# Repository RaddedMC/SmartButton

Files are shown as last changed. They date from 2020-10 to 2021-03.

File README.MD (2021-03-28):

# RaddedMC's SmartButton
This project is currently a work-in-progress. Most things work but there are a few small things to be ironed out...
Requirements:
 - An ESP32 or ESP8266 Microcontroller
 - An internet connection / WiFi router
 - Some webhooks!
 - Some kind of button -- the PCB is designed for a stanard 6x6mm tactile switch
 - Also helpful to have an LED and/or passive piezo -- the PCB is designed for a Murata PKMCS0909E4000-R1
 - Two resistors; values will vary, but the schematic has a 220 and 320 ohm. Use a resistor appropriate for your LED
 
Instructions:
 - Build the below circuit:
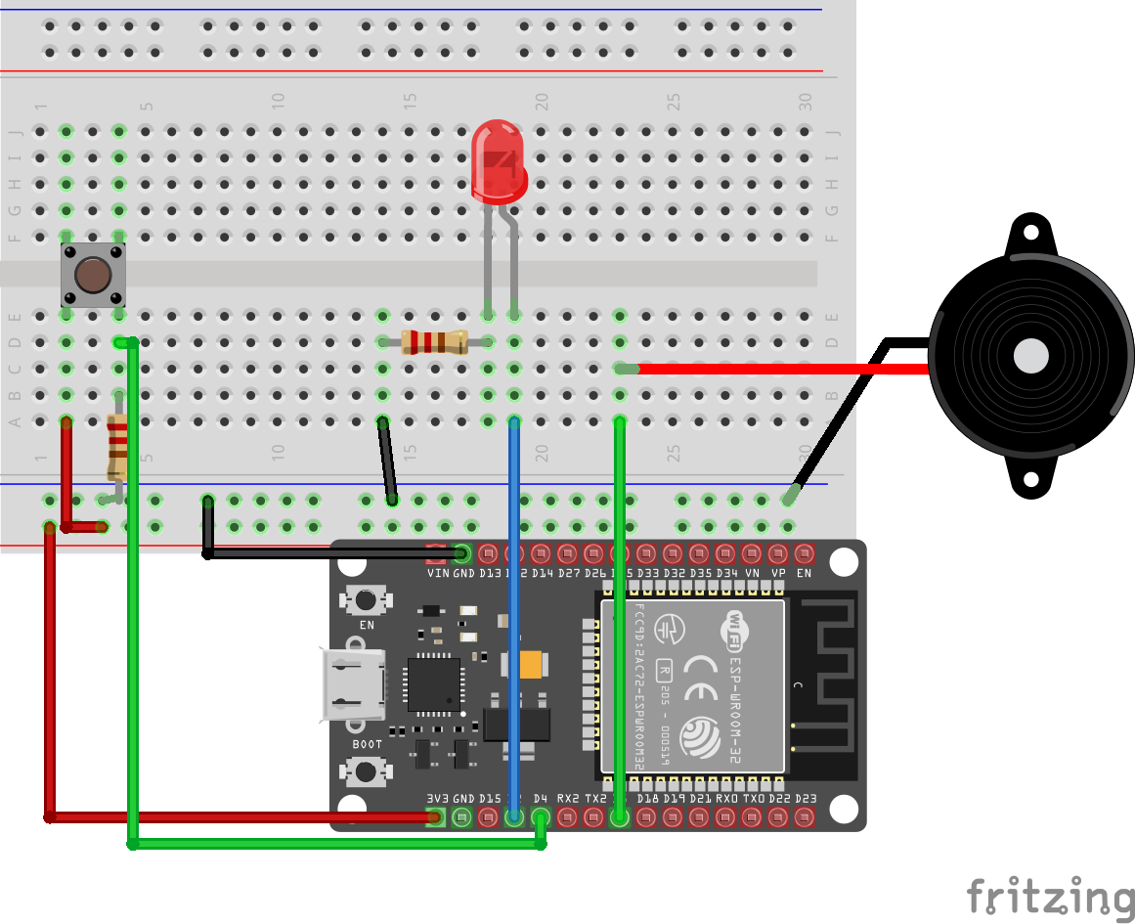
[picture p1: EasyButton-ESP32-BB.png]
Fritzing diagram of RaddedMC's SmartButton circuit
 
   - If you're using an ESP8266 NodeMCU, substitute D2, D4, and D6 with the pins labelled D4, D2, and D1 respectively. The LED resistor is 320 ohm and the button pulldown resistor is 220 ohm, however, these are not strict values
   - **OR** use the PCB in the PCB folder, credits to kelvinhall05 for the design!
 - Clone the EasyButton.ino file that matches your board
 - Make sure your Arduino IDE is set up for an ESP32 or ESP8266 NodeMCU board
 - Set Wifi SSID and password, and set up webhooks of your choosing (make sure that you use http:// in your URL as opposed to https://. 
 - You can change pins to whatever you like. Helpful if you want the ESP's built-in LED to blink when you do things or if you want to use one of the touch sensor pins instead of a boring clicky button. Pinout is currently configured for both boards to be compatible with one PCB.
 
**As mentioned, this project is a work in progress. Suggestions are appreciated, and these instructions might change over time.**

Feel free to dm me on Insta @RaddedMC or Discord at RaddedMC#4791 for any questions. Video for this project is in the works!

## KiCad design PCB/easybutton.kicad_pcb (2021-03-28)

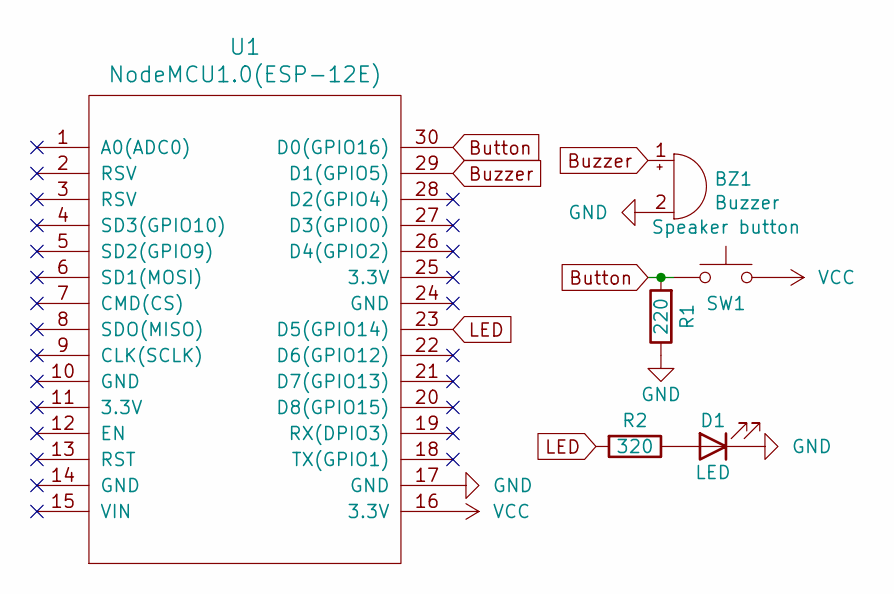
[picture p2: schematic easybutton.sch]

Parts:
BZ1: Buzzer; Buzzer_Murata_PKMCS0909E4000-R1
D1: LED; LED_D5.0mm
R1: 220; R_Axial_DIN0207_L6.3mm_D2.5mm_P10.16mm_Horizontal
R2: 320; R_Axial_DIN0207_L6.3mm_D2.5mm_P10.16mm_Horizontal
SW1: Speaker button; SW_PUSH_6mm
U1: NodeMCU1.0(ESP-12E); NodeMCU-LoLinV3

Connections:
Button: R1.2, SW1.1, U1.30 (D0(GPIO16))
Buzzer: BZ1.1 (-), U1.29 (D1(GPIO5))
GND: BZ1.2 (+), D1.1 (K), R1.1, U1.17 (GND)
LED: R2.2, U1.23 (D5(GPIO14))
unnamed: D1.2 (A), R2.1
VCC: SW1.2, U1.16 (3.3V)

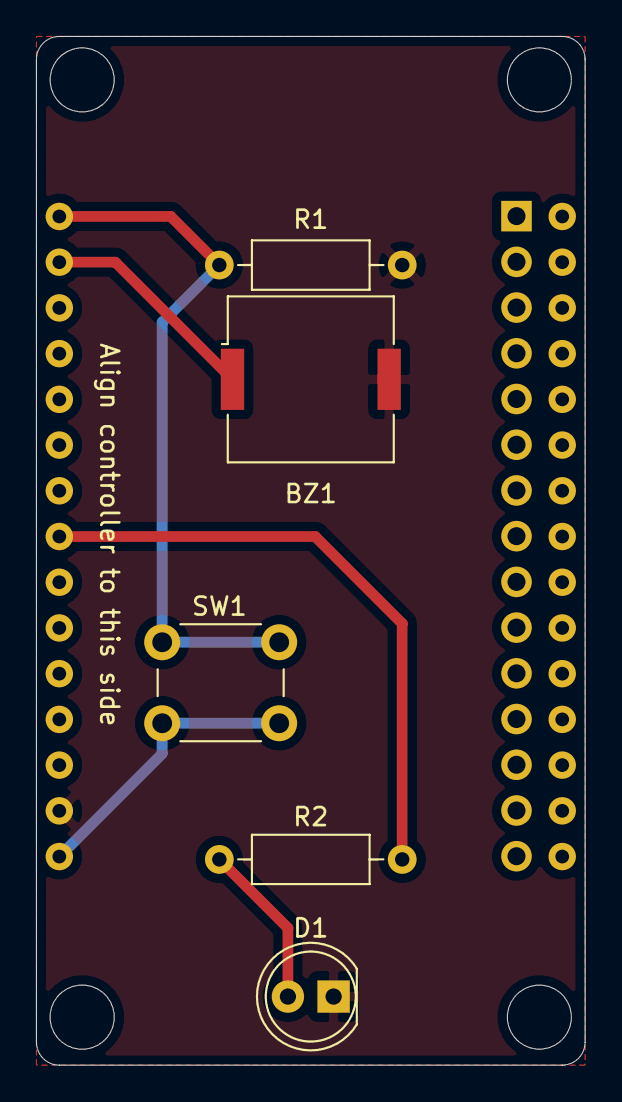
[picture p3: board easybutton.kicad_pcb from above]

Board: 2 copper layers, 30.5 x 57.2 mm, 6 parts (1 on the bottom side), 6 nets.

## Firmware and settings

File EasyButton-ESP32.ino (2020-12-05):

//EasyButton.ino for ESP32 -- RaddedMC


// META
#include <WiFi.h>
#include <HTTPClient.h>
const int BUTTON_PIN = 23;
const int BUZZER_PIN = 22;
const String WIFI_SSD = "Not2";
const String WIFI_PWD = "845NotNewpass7910";
const int LED_PIN = 5;

void printline(int spacing) {
  for (int i = 0; i != 30; i++) {
    if (i % spacing == 0) {
      Serial.print('-');
    } else {
      Serial.print(' ');
    }
  }
  Serial.println();
}
void printline() {
  printline(1);
}

// USER RESPONSE
void beep(int soundNum) {
  switch (soundNum) {
    case 0:
      // generic boop
      ledcWriteTone(0, 400);
      digitalWrite(LED_PIN, HIGH);
      delay(60);
      ledcWriteTone(0, 0);
      digitalWrite(LED_PIN, LOW);
      delay(100);
      break;
    case 1:
      // success tone 1 -- on
      ledcWriteTone(0, 400);
      digitalWrite(LED_PIN, HIGH);
      delay(100);
      ledcWriteTone(0, 0);
      digitalWrite(LED_PIN, LOW);
      delay(30);
      ledcWriteTone(0, 1000);
      digitalWrite(LED_PIN, HIGH);
      delay(80);
      ledcWriteTone(0, 0);
      digitalWrite(LED_PIN, LOW);
      delay(100);
      break;
    case 2:
      // fail tone
      ledcWriteTone(0, 1000);
      digitalWrite(LED_PIN, HIGH);
      delay(80);
      ledcWriteTone(0, 0);
      digitalWrite(LED_PIN, LOW);
      delay(100);
      ledcWriteTone(0, 400);
      digitalWrite(LED_PIN, HIGH);
      delay(400);
      ledcWriteTone(0, 0);
      digitalWrite(LED_PIN, LOW);
      delay(100);
      break;
    case 3:
      // boot tone
      //Megalovania?? yup https://github.com/AnonymousAlly/Arduino-Music-Codes/blob/master/Megalovania.ino
      ledcWriteTone(0,294);//D4
      digitalWrite(LED_PIN, HIGH);
      delay(125);
      ledcWriteTone(0, 0);
      digitalWrite(LED_PIN, LOW);
      delay(125);
      ledcWriteTone(0,294);//D4
      digitalWrite(LED_PIN, HIGH);
      delay(125);
      ledcWriteTone(0, 0);
      digitalWrite(LED_PIN, LOW);
      delay(125);
      ledcWriteTone(0,587);//D5
      digitalWrite(LED_PIN, HIGH);
      delay(250);
      ledcWriteTone(0, 0);
      digitalWrite(LED_PIN, LOW);
      delay(250);
      ledcWriteTone(0,440);//A4
      digitalWrite(LED_PIN, HIGH);
      delay(250);
      ledcWriteTone(0, 0);
      digitalWrite(LED_PIN, LOW);
      delay(250);
      break;
    case 4:
      // boop2
      ledcWriteTone(0, 800);
      digitalWrite(LED_PIN, HIGH);
      delay(50);
      ledcWriteTone(0, 0);
      digitalWrite(LED_PIN, LOW);
      delay(100);
      break;
    case 5:
      // success tone 2 -- off
      ledcWriteTone(0, 1000);
      digitalWrite(LED_PIN, HIGH);
      delay(100);
      ledcWriteTone(0, 0);
      digitalWrite(LED_PIN, LOW);
      delay(30);
      ledcWriteTone(0, 400);
      digitalWrite(LED_PIN, HIGH);
      delay(80);
      ledcWriteTone(0, 0);
      digitalWrite(LED_PIN, LOW);
      delay(100);
      break;
  }
}


// INIT
void setup() {
  // Begin startup
  Serial.begin(115200);
  printline();
  Serial.println("Initializing SmartButton...");
  printline();

  // Set pins
  Serial.print("Setting pin ");
  Serial.print(BUTTON_PIN);
  Serial.println(" to button pin...");
  pinMode(BUTTON_PIN, INPUT);
  
  Serial.print("Setting pin ");
  Serial.print(BUZZER_PIN);
  Serial.println(" to buzzer pin...");
  pinMode(BUZZER_PIN, OUTPUT);
  ledcSetup(0, 400, 10);
  ledcAttachPin(BUZZER_PIN, 0);
  
  Serial.print("Setting pin ");
  Serial.print(LED_PIN);
  Serial.println(" to LED pin...");
  pinMode(LED_PIN, OUTPUT);

  // Connect Wi-Fi
  Serial.print("Connecting to ");
  Serial.print(WIFI_SSD);
  WiFi.begin(WIFI_SSD.c_str(), WIFI_PWD.c_str());
  while (WiFi.status() != WL_CONNECTED) {
    delay(500);
    Serial.print(".");
  }
  Serial.println();
  Serial.print("Connected! IP address: ");
  Serial.println(WiFi.localIP());

  // Setup complete.
  Serial.println("Setup completed. SmartButton is ready!");
  beep(3);
  printline();
}


// INTERNET
// Interval handler -- what to do after X intervals?
bool CRLights = false;
bool HWLights = false;
bool CRGH = false;
bool CRHWDesk = false;
HTTPClient http;

int sendWebRequest(const char * url) {
  http.begin(url);
  //http.setTimeout(1);
  int httpCode = http.GET();
  Serial.print("Web request returned code ");
  Serial.print(httpCode);
  Serial.println(".");
  return httpCode;
}

void toggleADevice(const char * urlOn, const char * urlOff, bool & state, const char * deviceName) {
  Serial.print("Toggling ");
  Serial.print(deviceName);
  Serial.println("...");
  if (state == false) {
    // Turn device ON
    Serial.println("Device is OFF.");
    Serial.print("Sending request to ");
    Serial.println(urlOn);
    if (sendWebRequest(urlOn) == 200) {
      beep(1);
      Serial.print(deviceName);
      Serial.println(" should now be ON.");
      state = true;
    } else {
      beep(2);
      Serial.println("Error! Device was probably not toggled");
    }
    
  } else {
    // Turn device OFF
    Serial.println("Device is ON.");
    Serial.print("Sending request to ");
    Serial.println(urlOff);
    if (sendWebRequest(urlOff) == 200) {
      beep(5);
      Serial.print(deviceName);
      Serial.println(" should now be OFF.");
      state = false;
    } else {
      beep(2);
      Serial.println("Error! Device was probably not toggled");
    }
  }
}

void determineAction(int intervals) {
  switch (intervals) {
    case 0: {
      // CompRoom lights
      // turn_on_light
      // turn_off_light
      beep(4);
      toggleADevice("[ON-HOOK]", "[OFF-HOOK]", CRLights, "Computer Room Lights");
    } break;
    case 1: {
      // Hall lights
      for (int i = 1; i != 0; i--) {
        beep(4);
      }
      toggleADevice("[ON-HOOK]", "[OFF-HOOK]", HWLights, "Basement Hallway Lights");
    } break;
    case 2: {
      // CompRoom GH
      // CGH_On
      // CGH_Off
      for (int i = 2; i != 0; i--) {
        beep(4);
      }
      toggleADevice("[ON-HOOK]", "[OFF-HOOK]", CRGH, "Computer Room Google Home Switch");
    } break;
    case 3: {
      // CompRoom HWDesk
      // Just_Lamp_On
      // Just_Lamp_Off
      for (int i = 3; i != 0; i--) {
        beep(4);
      }
      toggleADevice("[ON-HOOK]", "[OFF-HOOK]", CRHWDesk, "Computer Room Homework Desk");
    } break;
    case 5: {
      // I'm entering
      Serial.println("You've triggered the 'I'm entering' routine:");
      printline(3);
      for (int i = 5; i != 0; i--) {
        beep(4);
      }
      const int leavingRoutineLinkC = 2;
      const char * leavingRoutineLinks[leavingRoutineLinkC] = {
        "[ON-HOOK]",
        "[ON-HOOK]"
      };
      for (int i = 0; i != leavingRoutineLinkC; i++) {
        Serial.print("Sending request to ");
        Serial.println(leavingRoutineLinks[i]);
        if (sendWebRequest(leavingRoutineLinks[i]) == 200) {
          beep(1);
          Serial.println("Webhook triggered!");
        } else {
          beep(2);
          Serial.print("Error! Webhook ");
          Serial.print(leavingRoutineLinks[i]);
          Serial.println(" was not triggered!");
        } 
      }
      CRLights = true;
      CRGH = true;
    } break;
    case 4: {
      // I'm leaving
      Serial.println("You've triggered the 'I'm leaving' routine:");
      printline(3);
      for (int i = 4; i != 0; i--) {
        beep(4);
      }
      const int leavingRoutineLinkC = 3;
      const char * leavingRoutineLinks[leavingRoutineLinkC] = {
        "[OFF-HOOK]",
        "[OFF-HOOK]",
        "[OFF-HOOK]"
      };
      for (int i = 0; i != leavingRoutineLinkC; i++) {
        Serial.print("Sending request to ");
        Serial.println(leavingRoutineLinks[i]);
        if (sendWebRequest(leavingRoutineLinks[i]) == 200) {
          beep(5);
          Serial.println("Webhook triggered!");
        } else {
          beep(2);
          Serial.print("Error! Webhook ");
          Serial.print(leavingRoutineLinks[i]);
          Serial.println(" was not triggered!");
        } 
      }
      CRLights = false;
      HWLights = true;
      CRGH = false;
      CRHWDesk = false;
    } break;
    default: {
      beep(4);
      beep(0);
      Serial.println("Nothing to do.");
    }
  }
}


int timeOff = 0;
int timeOffInterval = 260000000;
int interval = 1000000;

// MAINLOOP
// Interval counter
void loop() {
  int currentState = digitalRead(BUTTON_PIN);
  int timeHeld = 1; // To eliminate interval zero
  int intervals = 0;
  if (currentState == HIGH) {
    timeOff = 0;
    while (currentState == HIGH) {
      timeHeld++;
      if (timeHeld % interval == 0) {
        beep(0);
        Serial.print("Held for ");
        intervals = timeHeld/interval;
        Serial.print(intervals);
        Serial.println(" intervals.");
      }
      currentState = digitalRead(BUTTON_PIN);
    }
    Serial.print("Released at ");
    Serial.print(intervals);
    Serial.println(" intervals.");
    printline(2);
    determineAction(intervals);
    printline();
  }
  else {
    timeOff++;
    if (timeOff % timeOffInterval == 0) {
        Serial.println("Sending blank ping...");
        
        sendWebRequest("192.168.1.1");
    }
  }
}

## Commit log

2020-10-25 First Commit Current code DOES work but I'd like to make some changes
2020-10-25 v1.1 -- Small updates Made LED and piezo react at the same moment rather than one before the other, making the SmartButton experience more responsive. Change the serial baud rate to the normal 115200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
2020-10-25 Added ESP8266 support! Also added a wiring diagram. Other changes have probably occurred as well.
2020-11-07 Pinout change for PCB I think this is the second time I've changed the 'default' pins for this project, but the new pinout that I've selected will use the same physical location on both the ESP8266 a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
2020-11-07 Added a PCB!
    PCB design credit to u/kelvinh_27. This PCB can be edited in kicad and should contain files that most fabs can accept for production.
2020-12-05 Small update For some reason after a long period of inactivity if I were to click my own personal SmartButton it would fail every time, and then work after a second press. Not exactly sure what's cau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
    [EasyButton-ESP32.ino, EasyButton-ESP8266.ino]
2021-03-28 Updating PCB, regenerating gerbers
    [easybutton-B_Cu.gbr, easybutton-B_Mask.gbr, easybutton-B_Paste.gbr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]
2021-03-28 Updating PCB and readme
    [easybutton-B_Cu.gbr, easybutton-B_Mask.gbr, easybutton-B_Paste.gbr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]
